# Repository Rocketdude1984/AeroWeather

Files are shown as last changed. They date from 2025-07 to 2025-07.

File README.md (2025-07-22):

# EchoWeather: DIY weather station and app
A personal project to design, build, and program a working weather station that connects to a database and smart phone app. Collected data will then be used to train an AI model that will predict future weather variables.

## Weather Variables

* Wind Speed
* Wind Direction
* Temperature
* Humidity
* Pressure
* Ambient Light
* UV Light
* Rain

## Components
1. XIAO ESP32C3: https://www.amazon.com/dp/B0DGX3LSC7?ref=ppx_yo2ov_dt_b_fed_asin_title&th=1
2. BME280 breakout module: https://www.amazon.com/dp/B0DHPCFJD6?ref=ppx_yo2ov_dt_b_fed_asin_title&th=1
3. AS5600 Magnetic Encoder: https://www.amazon.com/dp/B094F8H591?ref=ppx_yo2ov_dt_b_fed_asin_title&th=1
4. TP4056 Lithium Battery Charging Module: https://www.amazon.com/dp/B098989NRZ?ref=ppx_yo2ov_dt_b_fed_asin_title
5. LTR390-UV Ultraviolet Sensor: https://www.amazon.com/dp/B0CHJL143Z?ref=ppx_yo2ov_dt_b_fed_asin_title&th=1
6. VEML7700 Ambient Light Sensor: https://www.amazon.com/dp/B09KGYF83T?ref=ppx_yo2ov_dt_b_fed_asin_title
7. 6V3W Waterproof Solar Panel: https://www.amazon.com/dp/B0CS364JGG?ref=ppx_yo2ov_dt_b_fed_asin_title&th=1

## Modules
The weather station will be built in 4 modules.
1. Power and basic variables (Main module)
2. Wind vane
3. Anemometer
4. Rain gauge

Each module will be connected together to the main module where all collected data will be sent to the cloud.

## Power
The station will be powered by a single 18650 (if more capacity is needed, 2 in parallel will be used later). To keep the battery charged, the station will have a built in 6V3W solar panel that charges the battery through a TP4056 charging module.

## Materials
Most of the station is printed with PETG which should be able to withstand fairly high outdoor temperatures and resist fading or cracking. 1" PVC pipe is used for the main support to hold each module of the station. For extra UV protection a few coats of white spray paint will be used.

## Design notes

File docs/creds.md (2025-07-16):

## References
Project inspired by: Nikodem Bartnik, Weather Station is The Best DIY Project EVER. https://youtu.be/U0kPgFcALac?si=J3OKKQZrQx6dV7NR

3D models: wt29, Anemometer, Windvane and Raingauge - 3D Printed and ESP8266 Enabled. Internet Connected and Logging. https://www.instructables.com/Anemometer-3D-Printed-With-Internet-Logging/

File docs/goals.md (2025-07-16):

# Project Goals

- [ ] Design, build, and program a small weather station using a variety of sensors.
- [ ] Construct station using 3D printable prints and cheap, commercially available parts.
- [ ] Design a smart phone app to display current weather variables.
- [ ] Build and deploy multiple stations across wide geographic area.
- [ ] Build and train AI model using collect weather data for future weather predictions.
- [ ] Update smart phone app to include predicted forecast.

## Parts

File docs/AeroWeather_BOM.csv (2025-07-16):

Option 1
Component | Quantity | Cost | Cost/unit | Average Current Draw (mA) | Voltage (V) | Notes
BME280 | 2 | $12.89 | $4.30 | 1 | 3.3 | Temperature, Humidity, Presurre
ESP32C3 Xiao | 3 | $19.99 | $6.66 | 5 | 3.3 | Controller
LTR390-UV | 1 | $14.60 | $14.60 | 3 | 3.3 | UV sensor
PETG filament | 1 | $15.60 | $15.60 | 0 | 0 | Anemometer, wind vane, enclosure
AS5600 | 3 | $9.99 | $3.33 | 3 | 3.3 | Rotary Senor
Bearings 4mmIDx8mmODx3mmH | 10 | $8.69 | $0.87 | 0 | 0 | Bearings
TP4056 | 6 | $9.11 | $1.52 | 0.2 | 5 | Charging and Boost Converter
VEML7700 | 2 | $12.99 | $6.50 | 0.05 | 3.3 | Light Sensor
6w solar panel | 1 | $18.99 | $18.99 | 0 | 6 | Solar Panel
1inOD PVC pipe | 1 | $5.41 | $5.41 | 0 | 0 | Mast
1inOD PVC 90 | 1 | $1.48 | $1.48 | 0 | 0 | Elbow
Krylon Spray Paint | 3 | $7.98 | $2.66 | 0 | 0 | UV protection
18650 Battery Holder | 5 | $5.98 | $1.20 | 0 | 0 | Holds the single 18650 cell
18650 Cells | 6 | $23.99 | $4.00 | 0 | 3.7 | Powers the station
 | Total Cost | $167.69 | $87.11

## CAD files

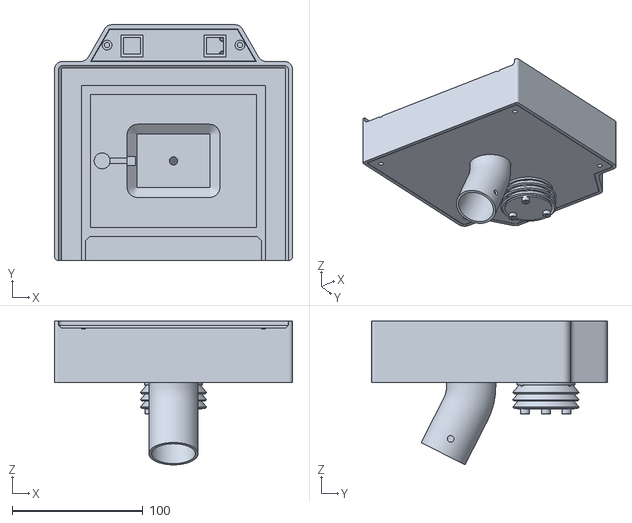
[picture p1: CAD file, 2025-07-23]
Parts/Main/Prints/EchoWeather_MainBox_parts/EchoWeather_Main_PREVIEW.stl
182.0 x 180.2 x 109.9

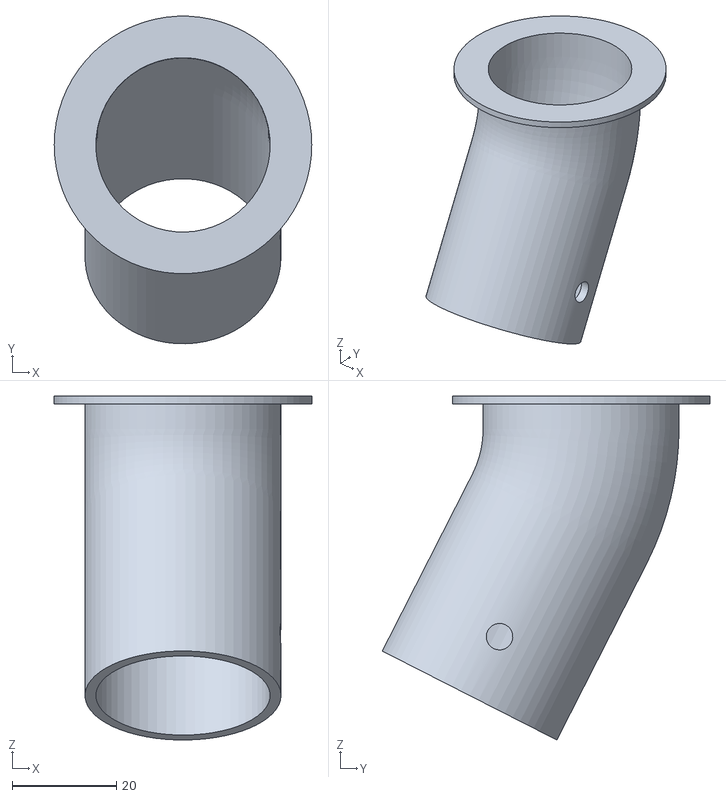
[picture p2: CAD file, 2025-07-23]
Parts/Main/Prints/EchoWeather_MainBox_parts/EchoWeather_Main_Coupler.stl
49.5 x 63.0 x 66.1

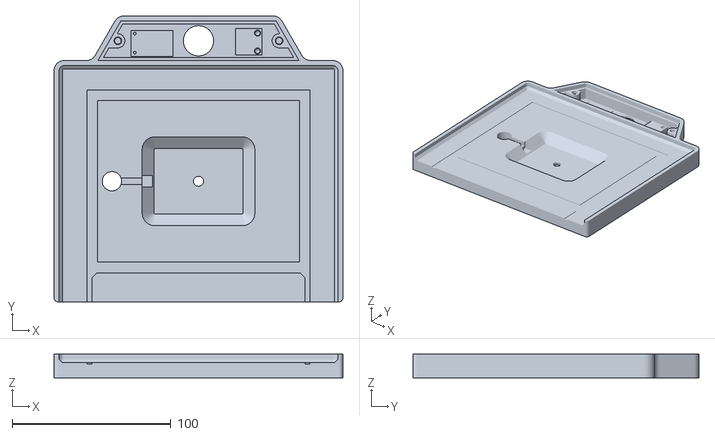
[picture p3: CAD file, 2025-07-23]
Parts/Main/Prints/EchoWeather_MainBox_parts/EchoWeather_Main_Lid.stl
182.0 x 180.2 x 15.0

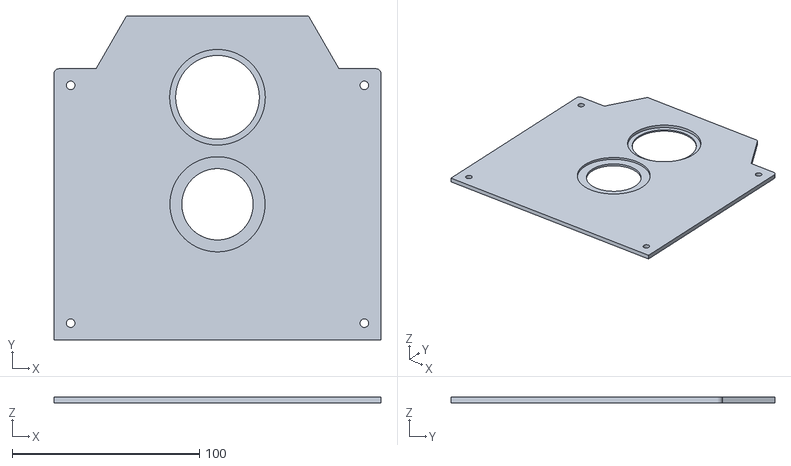
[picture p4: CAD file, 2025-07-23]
Parts/Main/Prints/EchoWeather_MainBox_parts/EchoWeather_Main_Bottom.stl
174.6 x 172.9 x 3.00

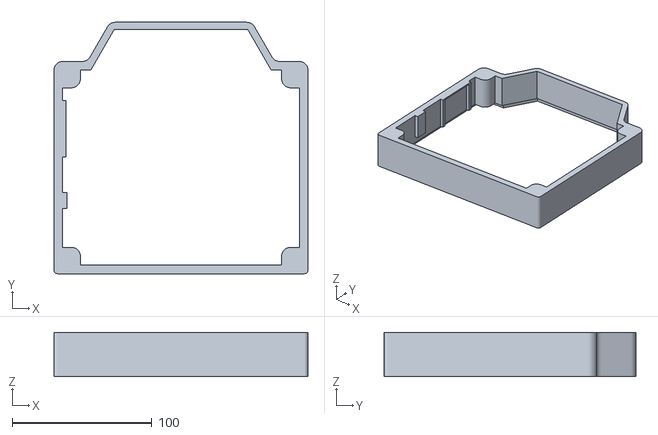
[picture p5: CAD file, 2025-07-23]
Parts/Main/Prints/EchoWeather_MainBox_parts/EchoWeather_Main_Enclosure.stl
182.0 x 180.2 x 31.8

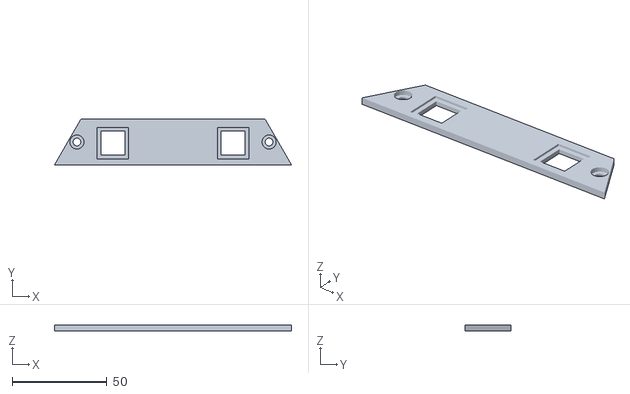
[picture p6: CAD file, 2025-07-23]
Parts/Main/Prints/EchoWeather_MainBox_parts/EchoWeather_Main_Cover.stl
125.3 x 24.1 x 3.00

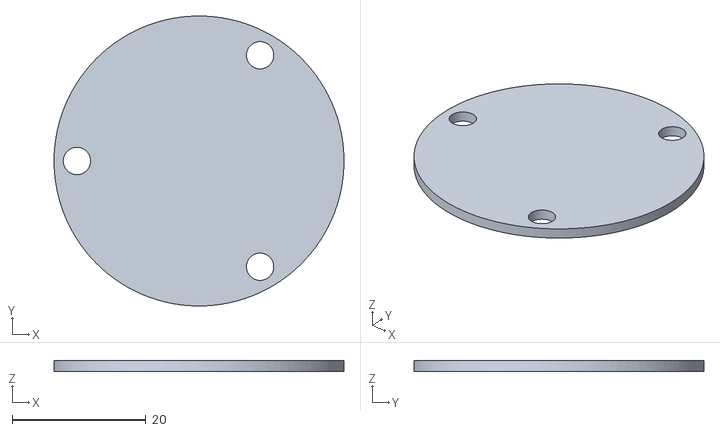
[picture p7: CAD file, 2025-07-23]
Parts/Main/Prints/EchoWeather_StevensonScreen_parts/EchoWeather_StevensonScreen_Bottom.stl
43.4 x 43.4 x 1.59

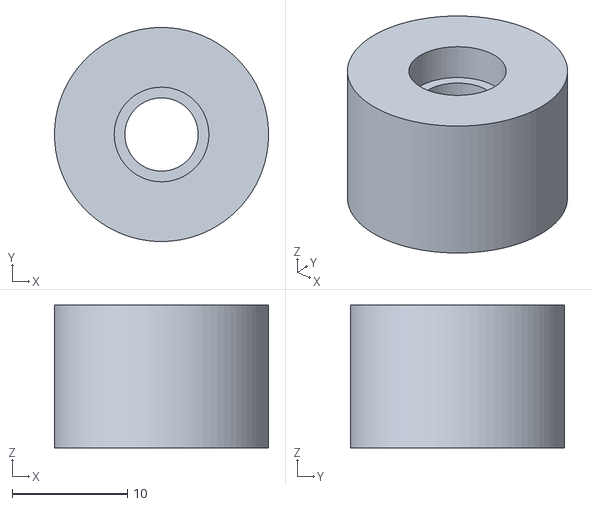
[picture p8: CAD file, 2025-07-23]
Parts/Windvane/WindVane_Print/Aeroweather_Windvane_InnerRotor.stl
18.5 x 18.5 x 12.3

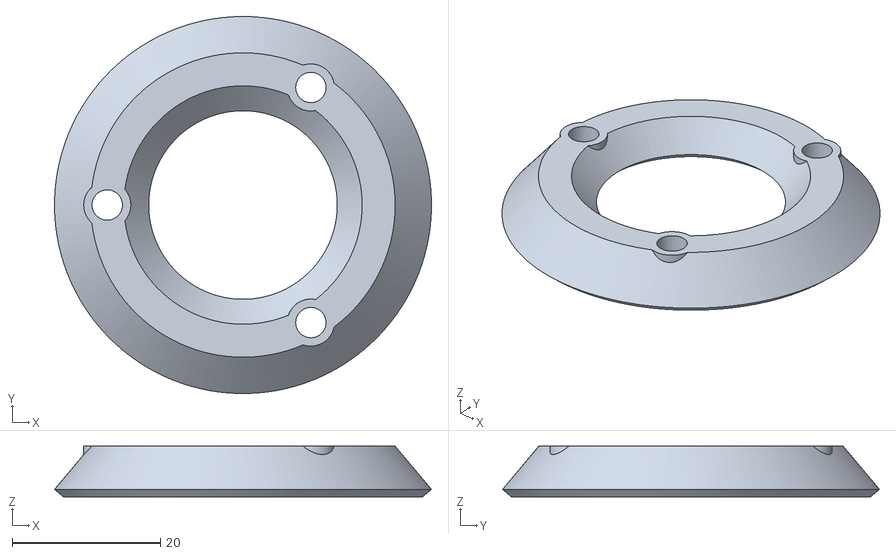
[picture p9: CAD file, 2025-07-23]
Parts/Main/Prints/EchoWeather_StevensonScreen_parts/EchoWeather_StevensonScreen_Ring.stl
50.8 x 50.8 x 6.86

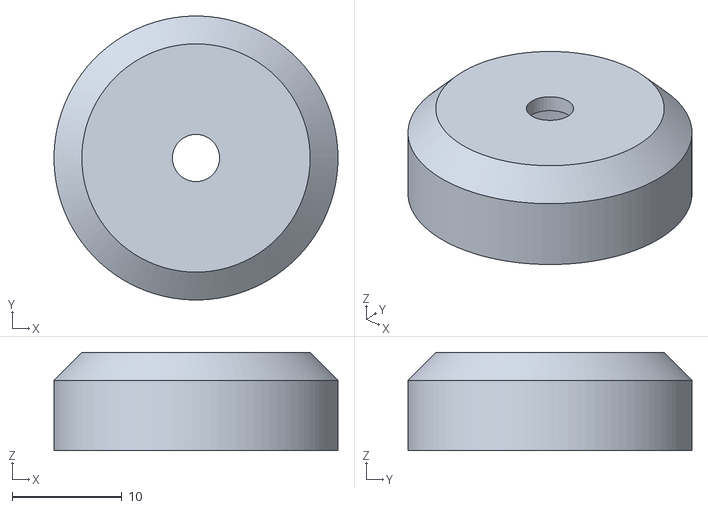
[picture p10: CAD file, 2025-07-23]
Parts/Windvane/WindVane_Print/Aeroweather_Windvane_OuterRotor.stl
25.9 x 25.9 x 8.95

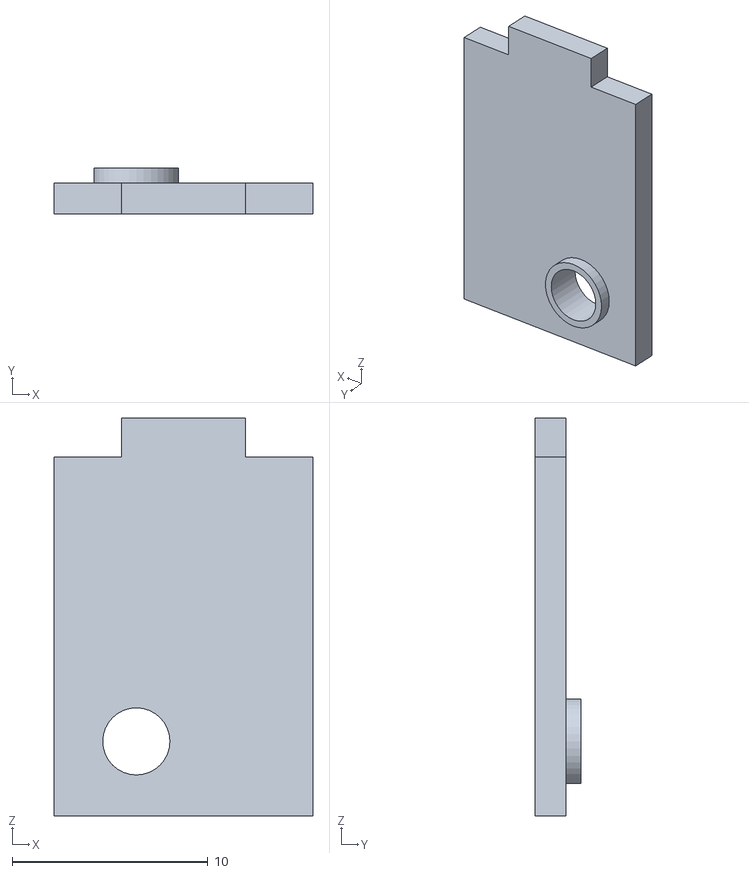
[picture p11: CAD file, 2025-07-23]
Parts/Main/Prints/EchoWeather_StevensonScreen_parts/EchoWeather_StevensonScreen_Holder.stl
13.2 x 2.35 x 20.3

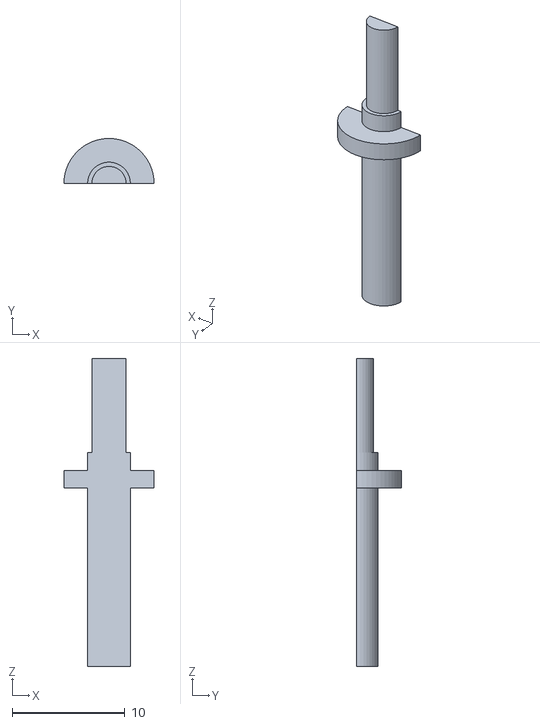
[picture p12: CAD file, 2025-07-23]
Parts/Windvane/WindVane_Print/Aeroweather_Windvane_Shaft.stl
8.00 x 4.00 x 27.3

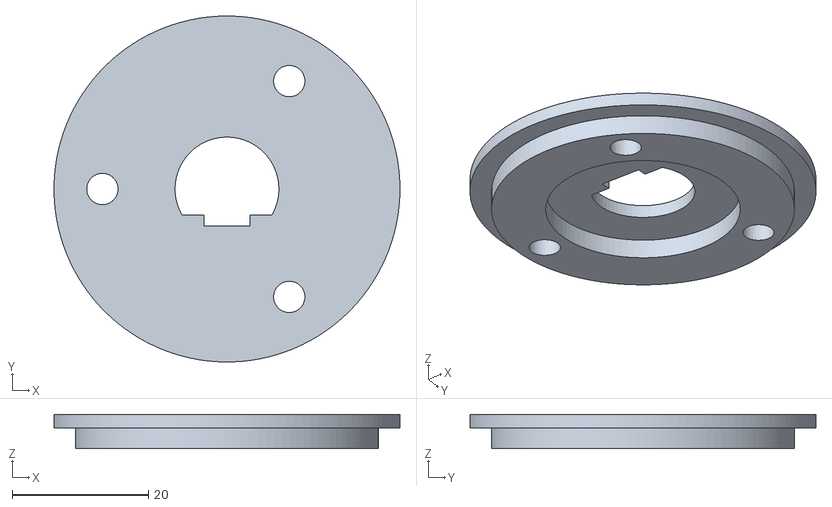
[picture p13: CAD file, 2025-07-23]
Parts/Main/Prints/EchoWeather_StevensonScreen_parts/EchoWeather_StevensonScreen_Adapter.stl
50.8 x 50.8 x 5.00

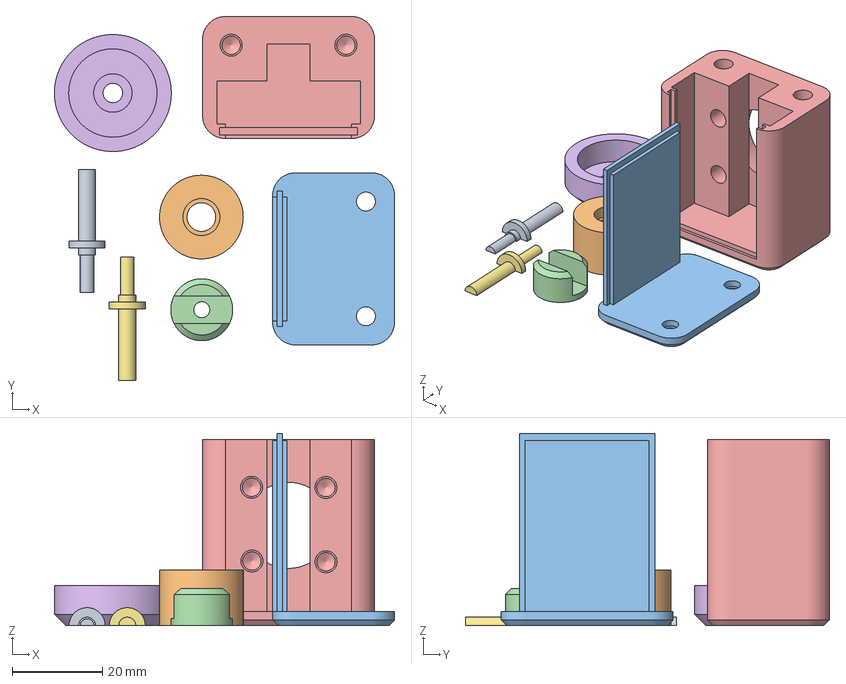
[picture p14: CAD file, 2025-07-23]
Parts/Windvane/WindVane_Print/AKMAX_Aeroweather_Windvane_Shaft.3mf
75.3 x 80.6 x 42.6 mm
Aeroweather_Windvane_Shaft.stl
Aeroweather_Windvane_InnerRotor.stl
Aeroweather_Windvane_Lid.stl
Aeroweather_Windvane_VaneHolder.stl
Aeroweather_Windvane_Enclosure.stl
Aeroweather_Windvane_OuterRotor.stl
Aeroweather_Windvane_Shaft.stl(1)

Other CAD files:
Parts/Main/Prints/EchoWeather_StevensonScreen_parts/AKMAX_EchoWeather_StevensonScreen.3mf
Parts/Windvane/WindVane_Print/Aeroweather_Windvane_VaneHolder.stl
Parts/Main/Prints/EchoWeather_StevensonScreen_parts/EchoWeather_StevensonScreen_PREVIEW.stl
Parts/Windvane/WindVane_Print/Aeroweather_Windvane_Enclosure.stl
Parts/Main/Models/EchoWeather_Main.f3z
Parts/Main/Models/EchoWeather_StevensonScreen.f3z
Parts/Windvane/WindVane_Print/Aeroweather_Windvane_Lid.stl

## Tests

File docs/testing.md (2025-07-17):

# Testing

The BME280, UV, and ambient light sensors were connected to the ESP32 via I2C and a simple program was created to check the sensor values and then display them on the serial monitor.

After testing each sensor the program was changed to upload the sensor values to a Google sheet [fig. 1]. After this was successful, the battery, charging module, and solar panel were connected to the setup and everything was mounted to a wooden board and pole for testing [fig. 2]. The testing rig was mounted about 4 feet above the ground to eliminate extra heat from radiation off the ground.

fig. 1

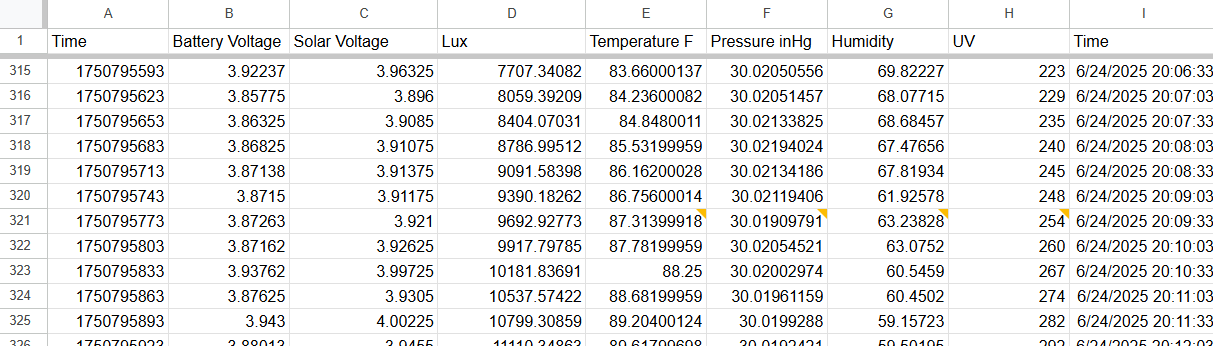
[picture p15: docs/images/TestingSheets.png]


fig. 2

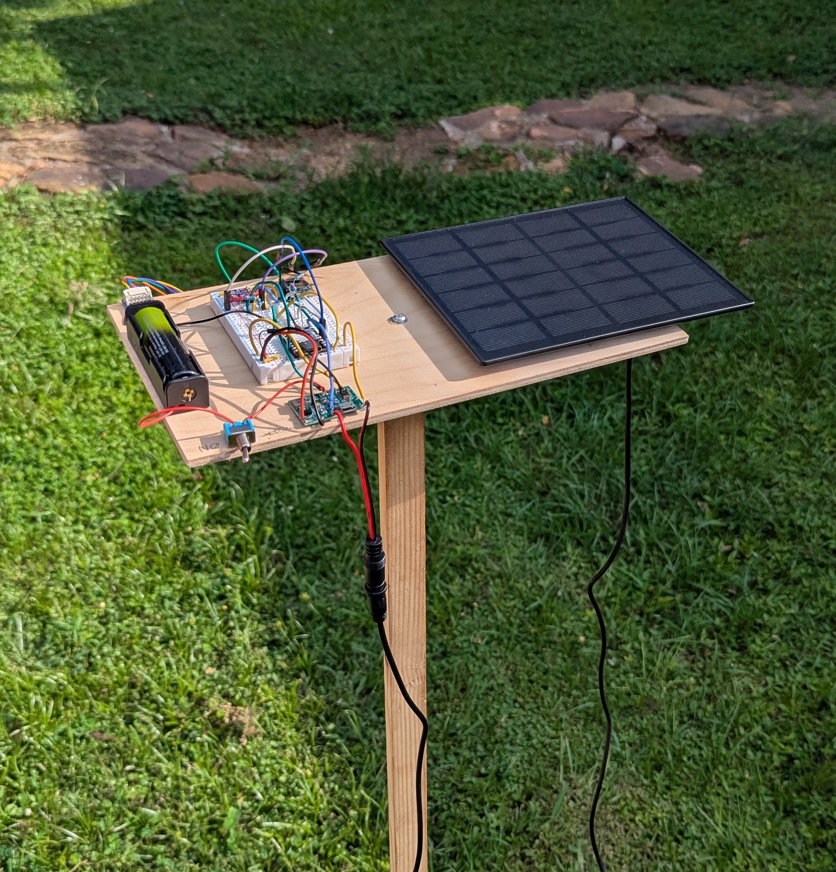
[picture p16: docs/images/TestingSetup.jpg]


After allowing the sensors to acclimate to the conditions it was found that the values for all the sensors will need calibration, but this will wait until everything is probably mounted in the final enclosure.

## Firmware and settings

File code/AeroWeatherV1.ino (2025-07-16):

#include <Arduino.h>
#include <WiFi.h>
#include "time.h"
#include <sys/time.h>
#include "creds.h"
#include <ESP_Google_Sheet_Client.h>
#include "Adafruit_VEML7700.h"
#include <Adafruit_BME280.h>
#include "DEV_Config.h"
#include "LTR390.h"
#include <Wire.h>
#include <Adafruit_Sensor.h>

// Timer variables
unsigned long lastTime = 0;  
unsigned long timerDelay = 60000; // 10000 for testing, 60000 for finished design

// Token Callback function
void tokenStatusCallback(TokenInfo info);

Adafruit_VEML7700 veml = Adafruit_VEML7700();

Adafruit_BME280 bme; // I2C
struct BMEData {
  float temperature;
  float pressure;
  float humidity;
};

UDOUBLE UV,ALS;

// NTP server to request epoch time
const char* ntpServer = "pool.ntp.org";

// Variable to save current epoch time
unsigned long epochTime; 
struct tm timeInfo;

// Function that gets current epoch time
time_t getTime() {
  time_t now;
  struct tm timeinfo;
  if (!getLocalTime(&timeInfo)) {
    //Serial.println("Failed to obtain time");
    return(0);
  }
  time(&now);
  return now;
}

void setup() {
  // initialize digital pin led as an output
  Serial.begin(115200);
  Serial.println();
  Serial.println();

  //Configure time
  configTime(0, 0, ntpServer);

  setenv("TZ", "CST6CDT,M3.2.0/2,M11.1.0/2", 1);
  tzset();  // Apply the new TZ setting

  GSheet.printf("ESP Google Sheet Client v%s\n\n", ESP_GOOGLE_SHEET_CLIENT_VERSION);

  pinMode(A0, INPUT);
  pinMode(A1, INPUT);

  // Connect to Wi-Fi
  WiFi.setAutoReconnect(true);
  WiFi.begin(ssid, password);
  Serial.print("Connecting to Wi-Fi");
    while (WiFi.status() != WL_CONNECTED) {
      Serial.print(".");
      delay(1000);              
    }
  Serial.println();
  Serial.print("Connected with IP: ");
  Serial.println(WiFi.localIP());
  Serial.println();

  // Set the callback for Google API access token generation status (for debug only)
  GSheet.setTokenCallback(tokenStatusCallback);

  // Set the seconds to refresh the auth token before expire (60 to 3540, default is 300 seconds)
  GSheet.setPrerefreshSeconds(10 * 60);

  // Begin the access token generation for Google API authentication
  GSheet.begin(CLIENT_EMAIL, PROJECT_ID, PRIVATE_KEY);

  //---------------------vemlSetup--------------------
  if (!veml.begin()) {
    Serial.println("Sensor not found");
    while (1);
  }
  Serial.println("Sensor found");
  veml.setLowThreshold(10000);
  veml.setHighThreshold(20000);
  veml.interruptEnable(true);

  //---------------------BMESetup-------------------
  unsigned status;
  status = bme.begin(0x76); 
  bme.setSampling(Adafruit_BME280::MODE_FORCED,
                    Adafruit_BME280::SAMPLING_X1, // temperature
                    Adafruit_BME280::SAMPLING_X1, // pressure
                    Adafruit_BME280::SAMPLING_X1, // humidity
                    Adafruit_BME280::FILTER_OFF   ); 
  if (!status) {
        Serial.println("Could not find a valid BME280 sensor, check wiring, address, sensor ID!");
        Serial.print("SensorID was: 0x"); Serial.println(bme.sensorID(),16);
        Serial.print("        ID of 0xFF probably means a bad address, a BMP 180 or BMP 085\n");
        Serial.print("   ID of 0x56-0x58 represents a BMP 280,\n");
        Serial.print("        ID of 0x60 represents a BME 280.\n");
        Serial.print("        ID of 0x61 represents a BME 680.\n");
        while (1) delay(10);
    }

  //------------------UVSetup----------------------
  if(LTR390_Init() != 0){
      Serial.print("init err!!!");
      while(1);
  }
  LTR390_SetIntVal(5, 20);

}

//----------------------LUX LEVEL-----------------
float getLuxLevel(){
  float lux = veml.readLux();
  uint16_t irq = veml.interruptStatus();
  if (irq & VEML7700_INTERRUPT_LOW) {
    Serial.println("** Low threshold");
  }
  if (irq & VEML7700_INTERRUPT_HIGH) {
    Serial.println("** High threshold");
  }
  delay(500);
  return lux;
}

//--------------------Temperature, Pressure, Humidity----------
BMEData getBMEData() {
  BMEData data;
  bme.takeForcedMeasurement();
  data.temperature = bme.readTemperature();         // °C
  data.pressure    = bme.readPressure()/ 100.0F;   // hPa
  data.humidity    = bme.readHumidity();            // %
  return data;
}

float getUVLevel() {
  float UVLevel = LTR390_UVS();
  return UVLevel;
}

void loop() {
// Call ready() repeatedly in loop for authentication checking and processing
    bool ready = GSheet.ready();

    if (ready && millis() - lastTime > timerDelay){
        lastTime = millis();

        FirebaseJson response;
        FirebaseJson valueRange;

        float batteryVoltage = checkBatteryVoltage();
        float solarVoltage = checkSolarVoltage();
        float lux = getLuxLevel();
        BMEData BMEvalues = getBMEData();
        float UV = getUVLevel();

        Serial.print("Lux = ");
  Serial.println(lux);

  Serial.print("Temperature C = ");
  Serial.print(BMEvalues.temperature);
  Serial.println(" °C");

  Serial.print("Temperature F = ");
  Serial.print(BMEvalues.temperature*1.8+32);
  Serial.println(" °F");

  Serial.print("Pressure = ");
  Serial.print(BMEvalues.pressure);
  Serial.println(" hPa");

  
  Serial.print("Pressure = ");
  Serial.print(BMEvalues.pressure*0.02952998057228);
  Serial.println(" inHg");

  Serial.print("Humidity = ");
  Serial.print(BMEvalues.humidity);
  Serial.println(" %");

  Serial.print("UV Level: "); 
  Serial.println(UV);

        
        // Get timestamp
        time_t epochTime = getTime();

        localtime_r(&epochTime, &timeInfo);        // or localtime_r(...) for local TZ
        Serial.printf("%04d-%02d-%02d  %02d:%02d:%02d UTC\n",
                timeInfo.tm_year + 1900,
                timeInfo.tm_mon  + 1,
                timeInfo.tm_mday,
                timeInfo.tm_hour,
                timeInfo.tm_min,
                timeInfo.tm_sec);
        

        valueRange.add("majorDimension", "COLUMNS");
        valueRange.set("values/[0]/[0]", epochTime);
        valueRange.set("values/[1]/[0]", batteryVoltage);
        valueRange.set("values/[2]/[0]", solarVoltage);
        valueRange.set("values/[3]/[0]", lux);
        valueRange.set("values/[4]/[0]", BMEvalues.temperature*1.8+32);
        valueRange.set("values/[5]/[0]", BMEvalues.pressure*0.02952998057228);
        valueRange.set("values/[6]/[0]", BMEvalues.humidity);
        valueRange.set("values/[7]/[0]", UV);

        // For Google Sheet API ref doc, go to https://developers.google.com/sheets/api/reference/rest/v4/spreadsheets.values/append
        // Append values to the spreadsheet
        bool success = GSheet.values.append(&response /* returned response */, spreadsheetId /* spreadsheet Id to append */, "Sheet1!A1" /* range to append */, &valueRange /* data range to append */);
        if (success){
            response.toString(Serial, true);
            valueRange.clear();
        }
        else{
            Serial.println(GSheet.errorReason());
        }
        Serial.println();
        Serial.println(ESP.getFreeHeap());
    }
}

float checkBatteryVoltage(){
  float Vbatt = 0;
  for(int i = 0; i < 16; i++) {
    Vbatt = Vbatt + analogReadMilliVolts(A0); // ADC with correction   
  }
  float Vbattf = 2 * Vbatt / 16 / 1000.0;     // attenuation ratio 1/2, mV --> V
  Serial.print("Battery Voltage: ");
  Serial.println(Vbattf, 2);
  
  return Vbattf;
}

float checkSolarVoltage(){
  float Vsolar = 0;
  for(int i = 0; i < 16; i++){
    Vsolar = Vsolar + analogReadMilliVolts(A1);
  }
  float Vsolarf = 4 * Vsolar / 16 / 1000.0;
  Serial.print("Solar Voltage: ");
  Serial.println(Vsolarf, 2);

  return Vsolarf;
}

void tokenStatusCallback(TokenInfo info){
    if (info.status == token_status_error){
        GSheet.printf("Token info: type = %s, status = %s\n", GSheet.getTokenType(info).c_str(), GSheet.getTokenStatus(info).c_str());
        GSheet.printf("Token error: %s\n", GSheet.getTokenError(info).c_str());
    }
    else{
        GSheet.printf("Token info: type = %s, status = %s\n", GSheet.getTokenType(info).c_str(), GSheet.getTokenStatus(info).c_str());
    }
}

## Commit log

2025-07-16 Adding MainBox stl
    This is just the current stl file, work in progress.
    [Aeroweather_MainBox.stl]
2025-07-16 adding Stevenson screen stl
    WIP
    [Aeroweather_SS.stl]
2025-07-16 Mainbox fusion file
    [Aeroweather_MainBox.f3z]
2025-07-16 Stevenson screen fusion file
    [Aeroweather_StevensonScreen.f3z]
2025-07-16 Adding BOM
    This list includes prices of components as of May 2025, some items are not used in the station. This list will be updated later.
    [AeroWeather_BOM.csv]
2025-07-23 Adding Second round of files
    Adding the second round of files for the main module. Parts for the main box and the Stevenson screen. The parts for the main box are all separated for printing, but I made a big file to print straig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
    [AKMAX_EchoWeather_StevensonScreen.3mf, EchoWeather_Main.f3z, EchoWeather_Main_Bottom.stl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]
2025-07-23 Uploading parts as one big folder
    These parts are for the main box, Stevenson screen, and Wind vane. This also sets up the file structure for the modules.
    [AKMAX_Aeroweather_Windvane_Shaft.3mf, AKMAX_EchoWeather_StevensonScreen.3mf, Aeroweather_Windvane_Enclosure.stl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]
